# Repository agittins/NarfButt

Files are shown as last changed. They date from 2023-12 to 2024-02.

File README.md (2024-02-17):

# NarfButt! An nRF51822 BTHome Button

This is (currently a proof-of-concept) implementation of the
[BTHome](https://bthome.io/) protocol for nRF51xx chips (in particular
the nRF51822).

The idea is to create a BLE (Bluetooth Low Energy) remote
control with buttons (and perhaps other sensors) that sends data to
HomeAssistant via ESPHome Bluetooth Proxies.

Using the BTHome protocol means that no integrations are required, and
the device will show up automatically in Home Asssistant ready for
creating automations.

```
  +----------+          +-----------+           +-----------+
  | NarfButt |          |  ESPHome  |           |   Home    |    **~*~*~**
  | Remote   | -(ble)-> | ble_proxy | -(wifi)-> | Assistant | -> * MaGiC *
  +----------+          +-----------+           +-----------+    **~*~*~**
```

My personal goal is to create super-affordable remote control buttons
for placing over the top of existing light switches etc for
home-automation projects.

## Status

- Proof of concept. Sends valid BTHome v2 unencrypted advertisements, with
  battery percentage level and a bogus temperature measurement that increments
  with each packet sent.

## uFAQ

- What's with the name?
  - [Narf!](https://pinkyandthebrain.fandom.com/wiki/Narf) is the nonsense-word
    exclamation / catchphrase of Pinky from Pinky and the Brain.
  - Butts are funny and very unprofessional.
  - nRF51822... nrf... Narf.
  - Button... Bluetooth... bt... butt
- Why not zigbee, zwave or wifi remotes?
  - Cost. I want 6 or so buttons for under AU$10. Tradfi buttons are
    sexy, but too expensive to replace lots of wall switches (for me,
    anyway).
  - Redundancy - zigbee networks have only one controller node, despite
    having redundant paths to that node. Using BLE Proxies means I have
    many (currently half a dozen or so) BLE receivers that forward their
    data via one of multiple wifi APs, at which point my ethernet
    network is pretty reliable. I don't know how zwave works, but see
    point 1 above.
  - Wifi's no good because of power consumption, as I want these remotes
    to be easily thrown anywhere around the house. A CR2032 in this device
    should last a year or so if I haven't left too many bugs in the
    code.
- What modules should I buy?
  - The cheapest I've found are the HOLYIOT-17051-NRF51822 which are a
    little breakout board with annoyingly small 2.0mm-pitched pins. They
    seem to work just fine. There are also some smaller modules with
    castellated edges which might be easier to mount - I plan to make a
    board layout for those too - oddly the smaller modules are a bit
    more expensive, but still quite cheap.

## Building the Firmware image

This is a platformIO project with VSCode plugins, so opening with with
VSCode is probaby going to give the smoothest experience to try it out.

Please forgive my atrocious C++ code, I'm a greybeard SysAdmin not a
programmer :-) PR's *VERY* welcome!

## Flashing

I use a clone STLink V2 flasher and OpenOCD.

This connects with just the `GND`, `3.3v`, `SWDIO` and `SWCLK` lines.

*Update! The built-in stlink flashing in vscode works.* Just doing a `build`
and `upload` cycle in vscode should get the firmware on to your device.
However, if you want to do it without vscode or do something more specific,
then...

The modules need to be
mass-erased before flashing. Sometimes this part is hard to get working,
but ultimately what I've found works is:

```shell
openocd -f interface/stlink-v2.cfg -f target/nrf51.cfg \
    -c "tcl_port disabled" \
    -c "init; reset halt; nrf51 mass_erase; reset halt;" \
    -c "program ./.pio/build/waveshare_ble400/firmware.hex; reset; exit"
```

(You can just run `./tools/flashit.sh` to run exactly the above, or some
later variant that I've forgotten to update here).

Currently I'm having issues running openocd interactively, it seems to
disconnect after a few seconds, but using the command above so it all
happens immediately is working fine for me.

## Building the Hardware

- There's a PCB layout in the <hardware-pcb> folder, which is my current
  design for a general-purpose 6-button switch for placing over existing
  light switches, or using as a stand-alone remote control. I expect to
  create some variations of this, in particular a version with a rotary
  encoder might be fun to play with.

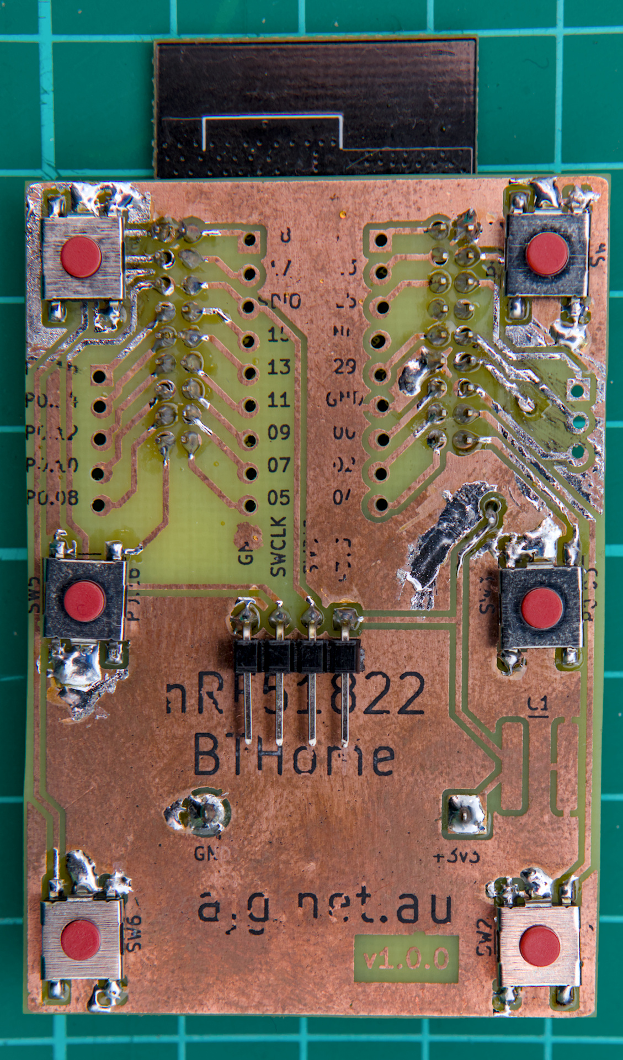
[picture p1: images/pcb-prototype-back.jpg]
PCB Prototype Back
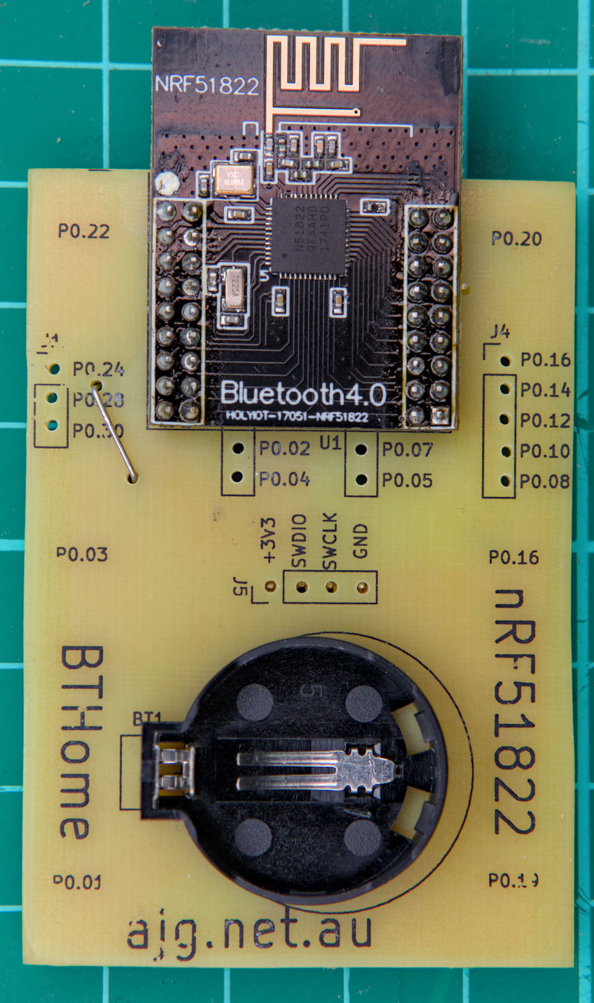
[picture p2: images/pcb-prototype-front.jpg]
PCB Prototype Front
 

- Note that the buttons are surface-mounted on the "back" while the NRF module
  is mounted on the non-trace side. This can be a bit confusing when doing
  the pcb layout!

## TODO's (please!)

- [ ] learn c.
- [ ] learn cpp.
- [ ] add buttons, sleep mode etc.
- [ ] turn this into a usable basis for my own and others' projects.
- [x] document how to build and flash a device (I think I used openOCD
  but frankly it was months ago and I am just whacking this up on GH
  now).
- [ ] Implement BTHomeV2 Encryption
- [ ] Fix module width in PCB design
- [ ] Try to take over the world.
  [Narf!](https://pinkyandthebrain.fandom.com/wiki/Narf)
- [ ] Choose a license. I haven't chosen a license yet. I need to check the sources I pilfered
  from (there are comments in the code) and choose a permissive license
  that fits the requirements of the ~~stolen code~~ prior art.

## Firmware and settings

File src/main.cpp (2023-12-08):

#include <Arduino.h>
#include <SPI.h>
#include <BLEPeripheral.h>

// This struct is based on the format defined at https://bthome.io/format/
//
// you should customise it to include the exact sensors that you want to
// advertise.
// The bleperipheral lib will already add the flags, localname and uuid16,
// so we add the deviceinfo flags and the individual sensor entries.
//
// Note that sensors should be added in numerical order of their ID.
// This one works (sort of) for sending via bleperipheral broadcast(),
// but is too restrictive (we can't bundle the name, flags etc)
struct BTHomeData {
  char devinfo = 0x40; // non-encrypted, v2 format
  const char flagtemp = 0x02; // temperature, decicelcius
  uint16_t temp = 2500;
};

static struct BTHomeData btHomeData;

void updateAdvertisingScanData();
unsigned char getBatteryLevel();

BLEPeripheral blePeripheral = BLEPeripheral();

BLEService bthomeService = BLEService("FCD2");
BLEFixedLengthCharacteristic bthome = BLEFixedLengthCharacteristic("FCD2", BLEBroadcast, sizeof(btHomeData));

unsigned long interval = 4000; // number of milliseconds between broadcast updates
unsigned long saved_stamp = 0; // millies stamp of last broadcast run.

const char localName[] = "NarfButt";
#define TX_POWER 0x04;
#define VBAT_MAX_IN_MV 3000
int g_counterValue = 3168;


void setup()
{
  //strcpy(btHomeData.name, (char *) "ajg-test");


  blePeripheral.setLocalName(localName);
  // name disappears if we disable connect :-/
  //blePeripheral.setConnectable(false);
//  blePeripheral.addAttribute(bthomeService);
//  blePeripheral.addAttribute(bthome);
  blePeripheral.begin();

  // delay the manual advdata update so we can get our name out there...
  saved_stamp = millis();
}

void loop()
{
  if ( (millis() - saved_stamp ) > interval ){
    saved_stamp = millis();

    // send btHome data via bleperipheral lib:
    /**
    btHomeData.temp ++;
    bthome.setValue( (unsigned char *)&btHomeData, sizeof(btHomeData) );
    bthome.broadcast();
    **/

    // send data via nrf direct call:
    btHomeData.temp ++;
    updateAdvertisingScanData();


    //sd_app_evt_wait();
  };

}

// lifted from https://github.com/sandeepmistry/arduino-BLEPeripheral/issues/272#issue-497748815
// and modified to suit
void updateAdvertisingScanData()
{
  static unsigned char srData[31];
  unsigned char srDataLen = 0;
  int scanDataSize = 5; // FIXME: must manually ensure this is more than the number of elements you add.
  BLEEirData scanData[scanDataSize];

  int i = 0;

  // - Flags
  scanData[i].length = 0x01;
  scanData[i].type = 0x01;
  scanData[i].data[0] = 0x06;


//**
  // - Local name
  i++;
  scanData[i].length = strlen(localName);
  scanData[i].type = 0x08;
  memcpy(scanData[i].data, localName, strlen(localName));
//**/


  // - BTHome Advertisement

  char bthomepacket[] = {
    // UUID
    0xD2, 0xFC, // UUID in reverse-byte order.

    // device info: bit0: encryption, bit5-7: version
    0x40, // v2, plaintext

    // BTHome Object entries. Ensure they are listed here in NUMERICAL order of type.

    // battery
    0x01, // battery %
    getBatteryLevel(),

    // temperature
    0x02, // temperature
    btHomeData.temp & 0xFF,
    btHomeData.temp >> 8 & 0xFF,

  };

  i++;
  scanData[i].length = sizeof(bthomepacket);
  scanData[i].type = 0x16; // 16bituuid service data
  memcpy(scanData[i].data, bthomepacket, sizeof(bthomepacket));

/**
  // - Tx Power
  i++;
  scanData[i].length = 1;
  scanData[i].type = 0x0A;
  scanData[i].data[0] = TX_POWER;

  // - Manufacturer Data
  i++;
  scanData[i].length = 2 + 4;
  scanData[i].type = 0xFF;
  // Manufacturer ID
  scanData[i].data[0] = 0xFF;
  scanData[i].data[1] = 0xFF;
  // Manufacturer data content
  scanData[i].data[2] = g_counterValue & 0xFF;
  scanData[i].data[3] = (g_counterValue >> 8) & 0xFF;
  scanData[i].data[4] = (g_counterValue >> 16) & 0xFF;
  scanData[i].data[5] = (g_counterValue >> 24) & 0xFF;
**/

  scanDataSize = i +1;

  if (scanDataSize && scanData)
  {
    for (int j = 0; j < scanDataSize; j++)
    {
      srData[srDataLen + 0] = scanData[j].length + 1;
      srData[srDataLen + 1] = scanData[j].type;
      srDataLen += 2;

      memcpy(&srData[srDataLen], scanData[j].data, scanData[j].length);

      srDataLen += scanData[j].length;
    }
  }

  // - Sets only avertising scan data
  sd_ble_gap_adv_data_set(srData, srDataLen, NULL, 0);
}


unsigned char getBatteryLevel(void)
{
  // Configure ADC
  NRF_ADC->CONFIG = (ADC_CONFIG_RES_8bit << ADC_CONFIG_RES_Pos) |
                    (ADC_CONFIG_INPSEL_SupplyOneThirdPrescaling << ADC_CONFIG_INPSEL_Pos) |
                    (ADC_CONFIG_REFSEL_VBG << ADC_CONFIG_REFSEL_Pos) |
                    (ADC_CONFIG_PSEL_Disabled << ADC_CONFIG_PSEL_Pos) |
                    (ADC_CONFIG_EXTREFSEL_None << ADC_CONFIG_EXTREFSEL_Pos);
  NRF_ADC->EVENTS_END = 0;
  NRF_ADC->ENABLE = ADC_ENABLE_ENABLE_Enabled;

  NRF_ADC->EVENTS_END = 0; // Stop any running conversions.
  NRF_ADC->TASKS_START = 1;

  while (!NRF_ADC->EVENTS_END)
  {
  }

  uint16_t vbg_in_mv = 1200;
  uint8_t adc_max = 255;
  uint16_t vbat_current_in_mv = (NRF_ADC->RESULT * 3 * vbg_in_mv) / adc_max;

  NRF_ADC->EVENTS_END = 0;
  NRF_ADC->TASKS_STOP = 1;
  NRF_ADC->ENABLE = ADC_ENABLE_ENABLE_Disabled;

  return (unsigned char)((vbat_current_in_mv * 100) / VBAT_MAX_IN_MV);
}

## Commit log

2023-11-19 Initial commit
    - initial proof-of-concept to create a firmware image
    for the nrf51822 that sends BTHome advertisement
    packets. Currently sensor values are faked, but the
    broadcasts work and are picked up by HomeAssistant
    and ESPHome ble-proxies.
2023-12-08 Initia PCB Design - HAS ISSUES!
    - The width of the module is too wide, making it hard to install the
    module and requiring pins to be bent to the sides awkwardly.
    [nrf51822-blehome.kicad_pcb, nrf51822-blehome.kicad_sch]
2024-02-17 (doc) Tidy readme and add images.
    - minor corrections to readme (formatting etc)
    - explain rename
    - clarify current project status
    - note that native vscode flashing works
    - info about PCB and images.
